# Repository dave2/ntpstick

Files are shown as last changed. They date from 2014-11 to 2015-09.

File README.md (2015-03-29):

ntpstick
========

NTPstick is a GPS-synced NTP server designed for low cost and ease
of deployment in places outside traditional datacentres.

The "stick" concept is that the board is expected to be placed into
a PVC tube at least 30mm I.D. with only an Ethernet cable reaching
the outside world carrying both Ethernet and poor-mans POE.

Structure
---------

This repo is divided into sections for different parts of the project:

 - hardware/ .. Contains the Kicad sources, schematics in PDF, and generated
   gerber files.
 - firmware/ .. Completed builds of the firmware, able to be flashed to 
   boards over TFTP
 - src/ .. Source code for the firmware.

Specifications
--------------

 - u.fl GPS antenna connection
 - uBlox MAX-M8Q GPS module (includes internal TCXO)
 - Atmel ATXMEGA128A4U MCU
 - 27MHz VCXO system clock
 - 12-bit DAC for VCXO control
 - WizNet W5500 Ethernet/IP chip
 - DC input on spare Ethernet pairs
 - DC-DC first stage, linear second stage PSU
 - Board is 113mm long, 30mm wide
 
License
-------

 - Please check each folder for the specific license applied, as they
   vary between sections of the project.

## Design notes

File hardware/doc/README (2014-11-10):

Contains various documents relating to the hardware.
May or may not be maintained. Schematics should be examined from 
the kicad source directory instead.

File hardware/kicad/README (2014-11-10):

Notes on Kicad source files for NTPstick
========================================

- These files require the current upstream source of Kicad to be read.
  In general, versions shipped with most distributions are not new 
  enough to read these files. At least r5256 is required from the Kicad
  source repo.

- I have not included separate libraries or footprints that were created
  for this project. I'll include them at some future point.

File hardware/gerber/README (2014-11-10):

********************************************************************
**                                                                **
**       W A R N I N G :   THESE FILES ARE NOT MAINTAINED         **
**                                                                **
********************************************************************

You should always generate gerbers from the Kicad source files. These
are here for reference about what versions were built at various stages.

DO NOT RELY ON THESE FILES FOR MANUFACTURE. ALWAYS GENERATE FROM KICAD.

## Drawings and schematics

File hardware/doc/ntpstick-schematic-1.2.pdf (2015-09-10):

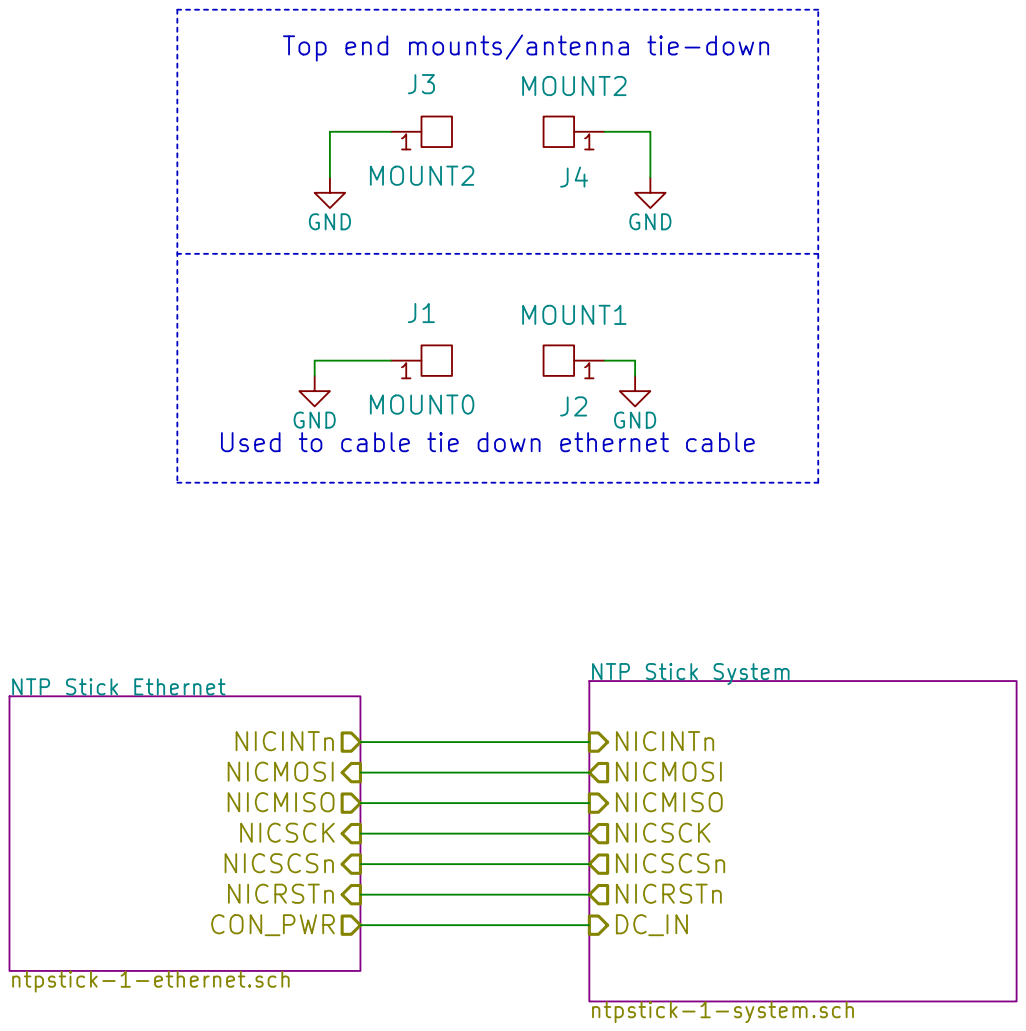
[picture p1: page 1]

1 J4 MOUNT2GND Top end mounts/antenna tie-down

1J1 MOUNT0
1 J2 MOUNT1 Used to cable tie down ethernet cable

File: ntpstick-1.sch Sheet: / hairy.geek.nz CC-NZ-3.0 BY-SA Not Production Proven NTP Stick Ethernet ntpstick-1-ethernet.sch

Id: 1/3 Title: NTP Stick 1.2

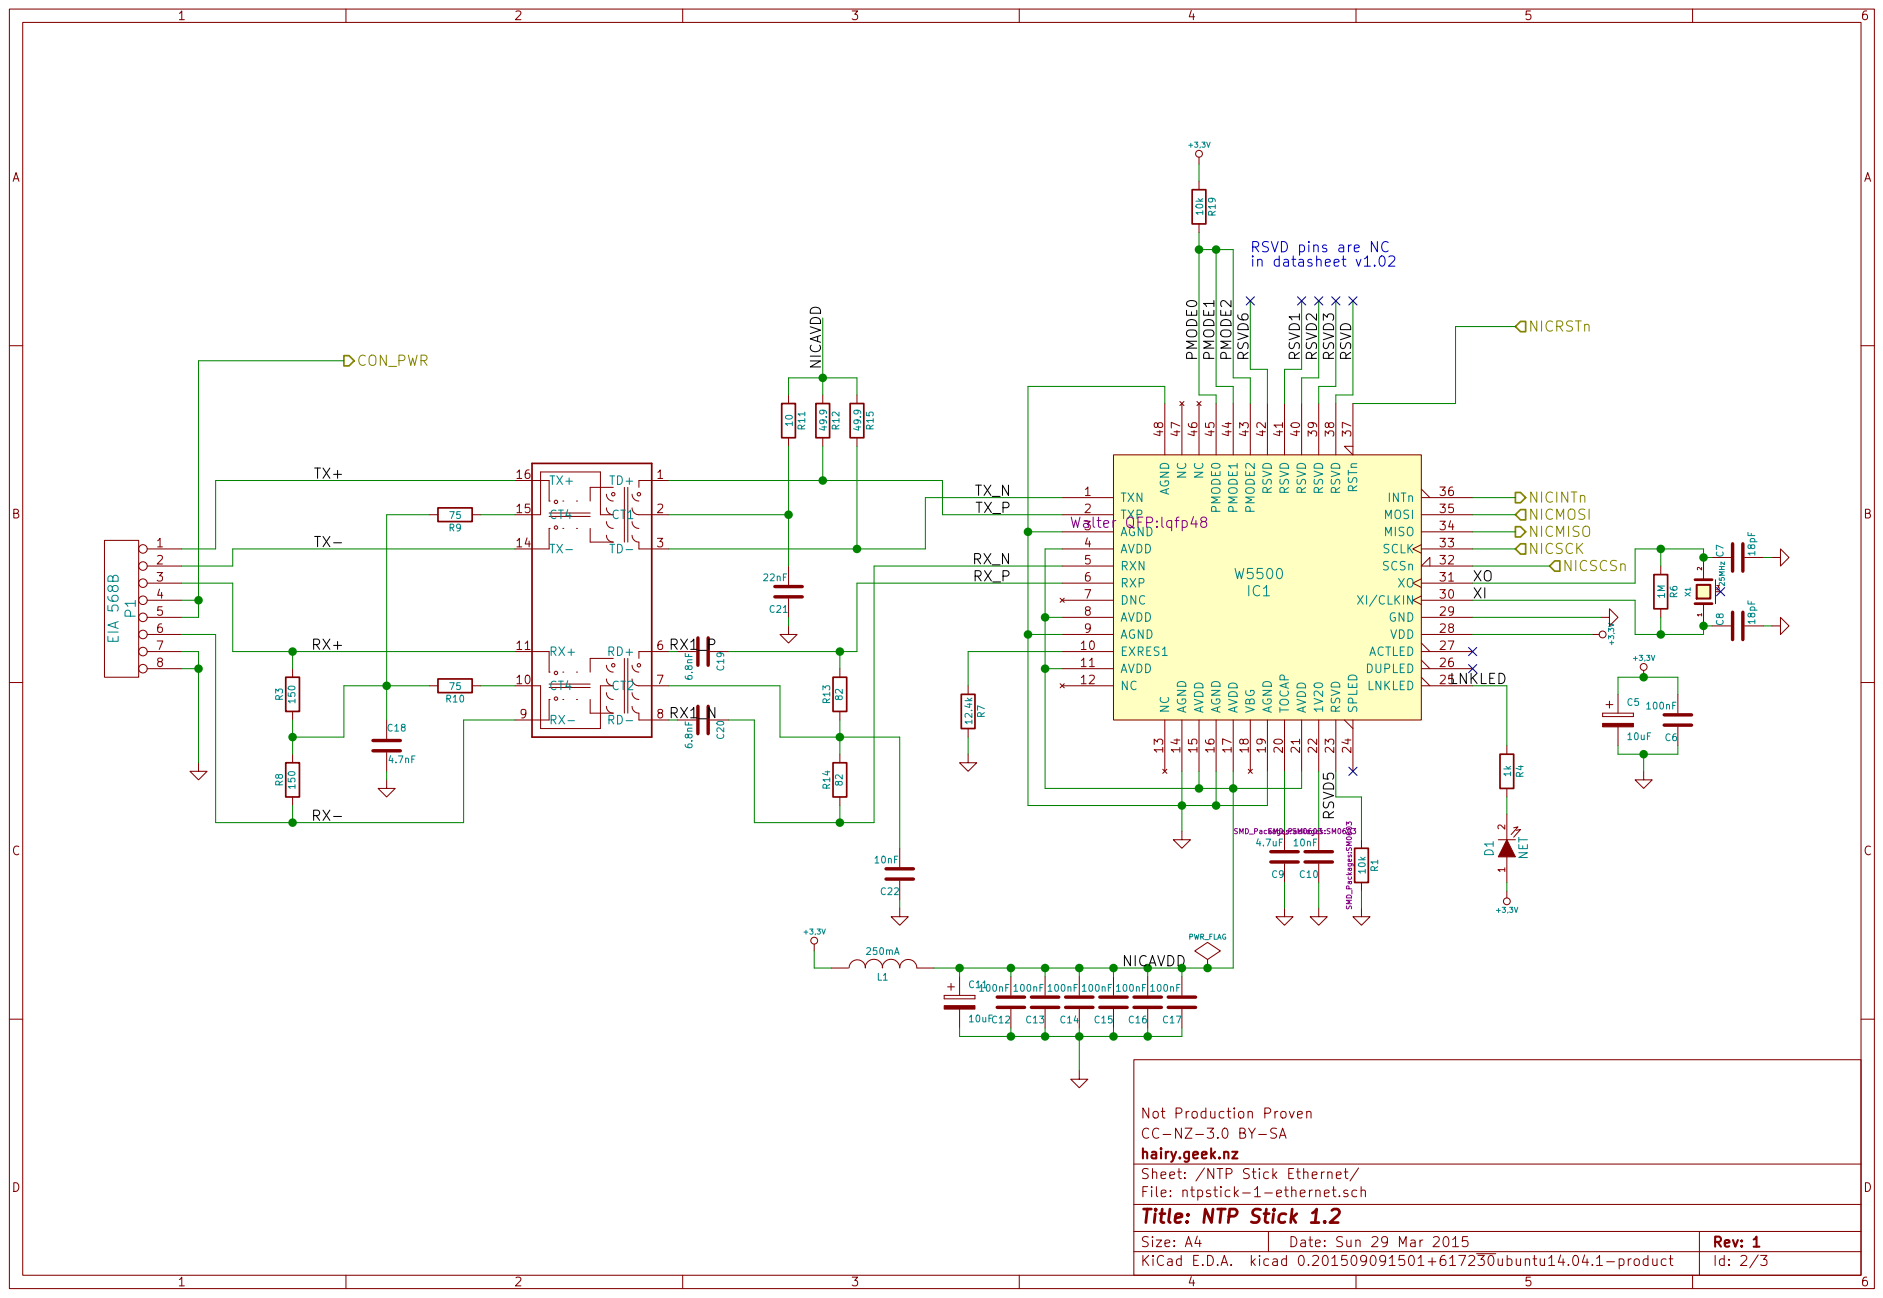
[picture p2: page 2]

RSVD pins are NC
in datasheet v1.02

RSVD1 RSVD2 RSVD3 RSVD RSVD5 IC1 W5500 Walter QFP:lqfp48 | XI PMODE0 PMODE1 PMODE2 RSVD6

File: ntpstick-1-ethernet.sch Sheet: /NTP Stick Ethernet/ hairy.geek.nz CC-NZ-3.0 BY-SA Not Production Proven

Id: 2/3 Title: NTP Stick 1.2

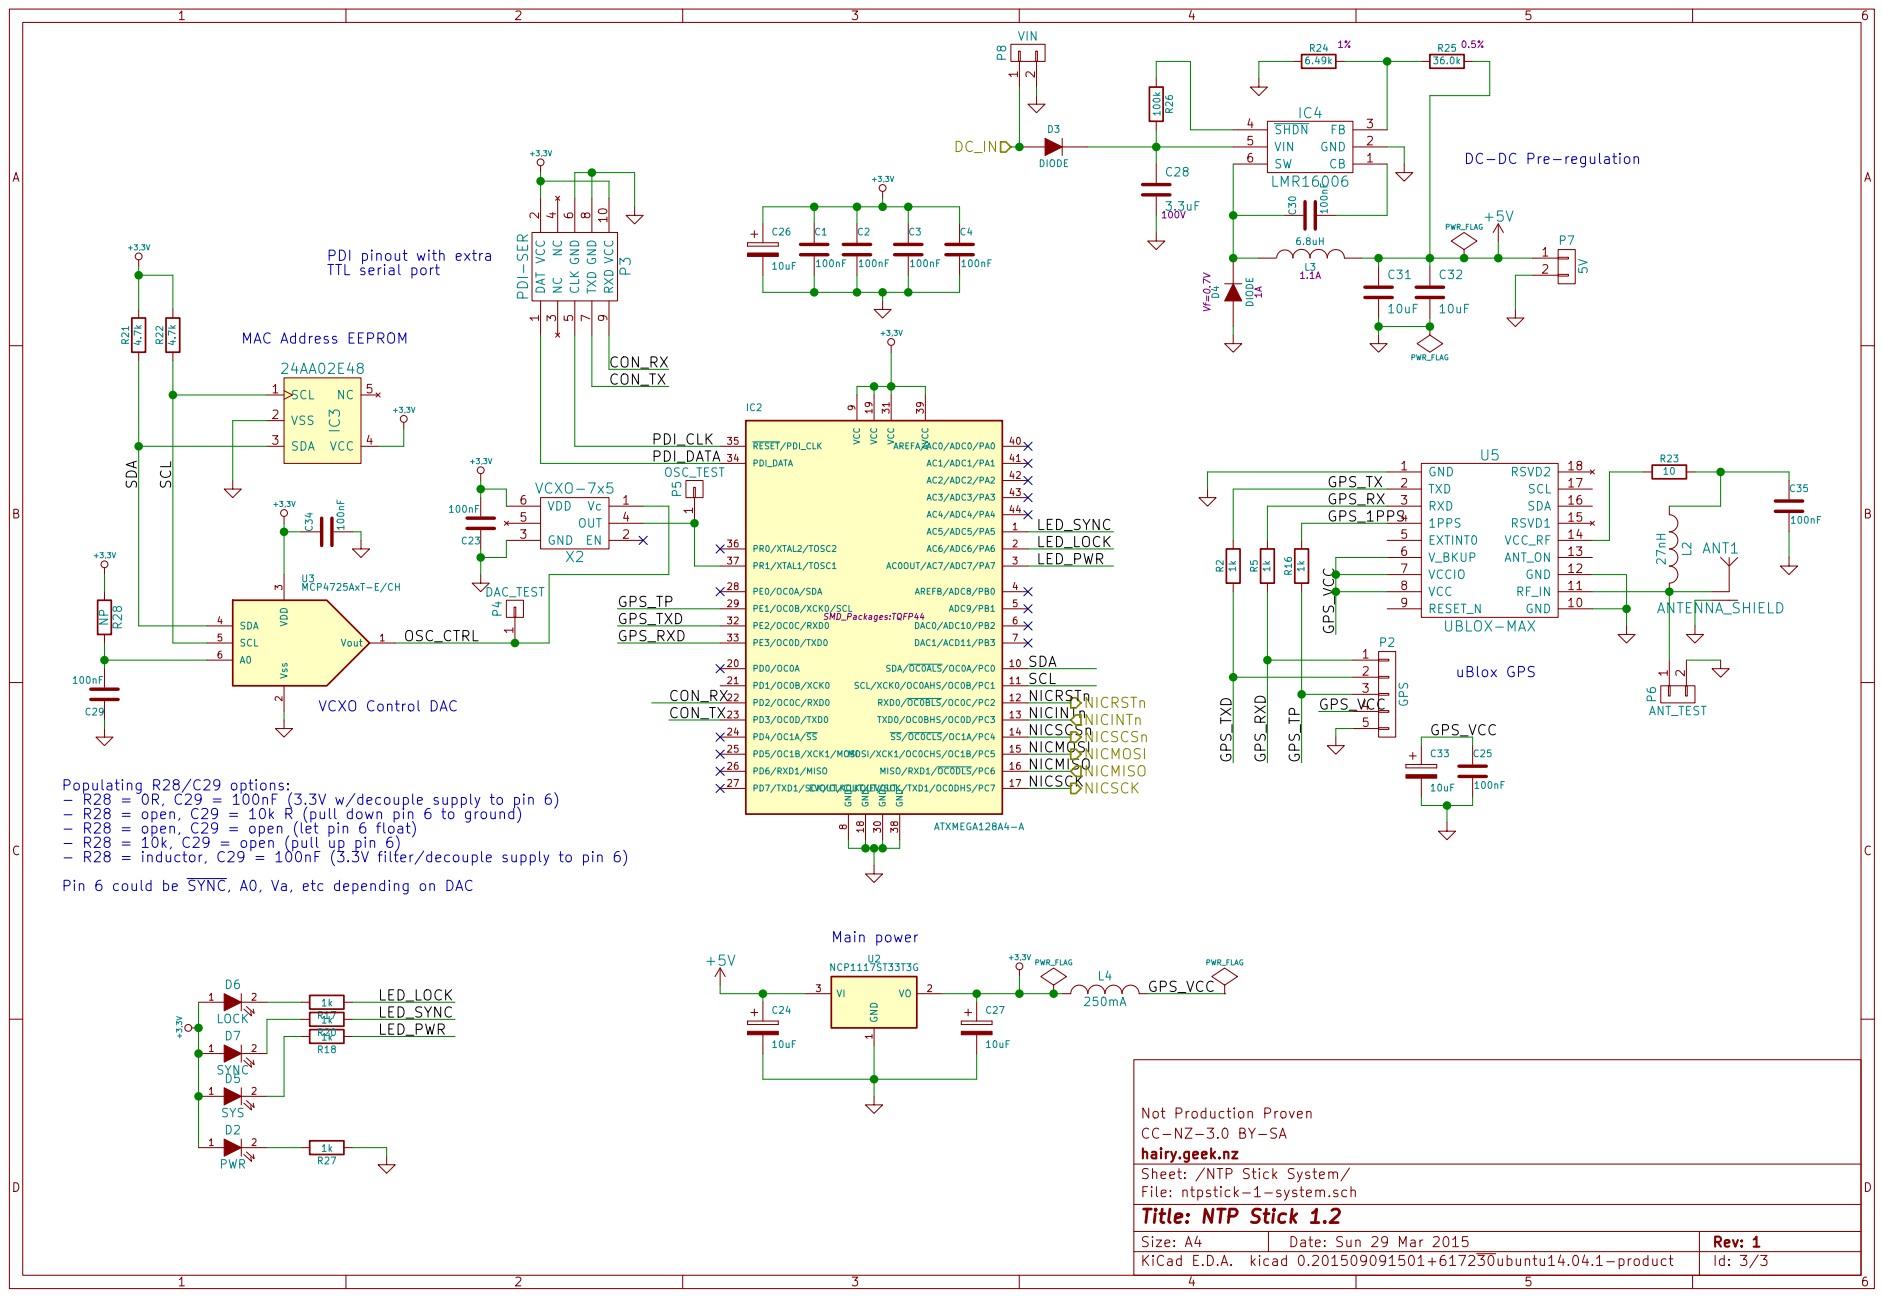
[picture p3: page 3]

DC-DC Pre-regulation

100nF VCXO Control DAC SCL

PDI pinout with extra

9 SDA/OC0ALS/OC0A/PC0 10 PD0/OC0A 20 GND 30 AREFA/AC0/ADC0/PA0 40 SCL/XCK0/OC0AHS/OC0B/PC1 11 PD1/OC0B/XCK0 21 VCC 31 AC1/ADC1/PA1 41 RXD0/OC0BLS/OC0C/PC2 12 PD2/OC0C/RXD0 22 PE2/OC0C/RXD0 32 AC2/ADC2/PA2 42

Populating R28/C29 options:
- R28 = 0R, C29 = 100nF (3.3V w/decouple supply to pin 6)
- R28 = open, C29 = 10k R (pull down pin 6 to ground)
- R28 = open, C29 = open (let pin 6 float)
- R28 = 10k, C29 = open (pull up pin 6)
- R28 = inductor, C29 = 100nF (3.3V filter/decouple supply to pin 6)

hairy.geek.nz CC-NZ-3.0 BY-SA Not Production Proven

Sheet: /NTP Stick System/
File: ntpstick-1-system.sch
Id: 3/3 Title: NTP Stick 1.2

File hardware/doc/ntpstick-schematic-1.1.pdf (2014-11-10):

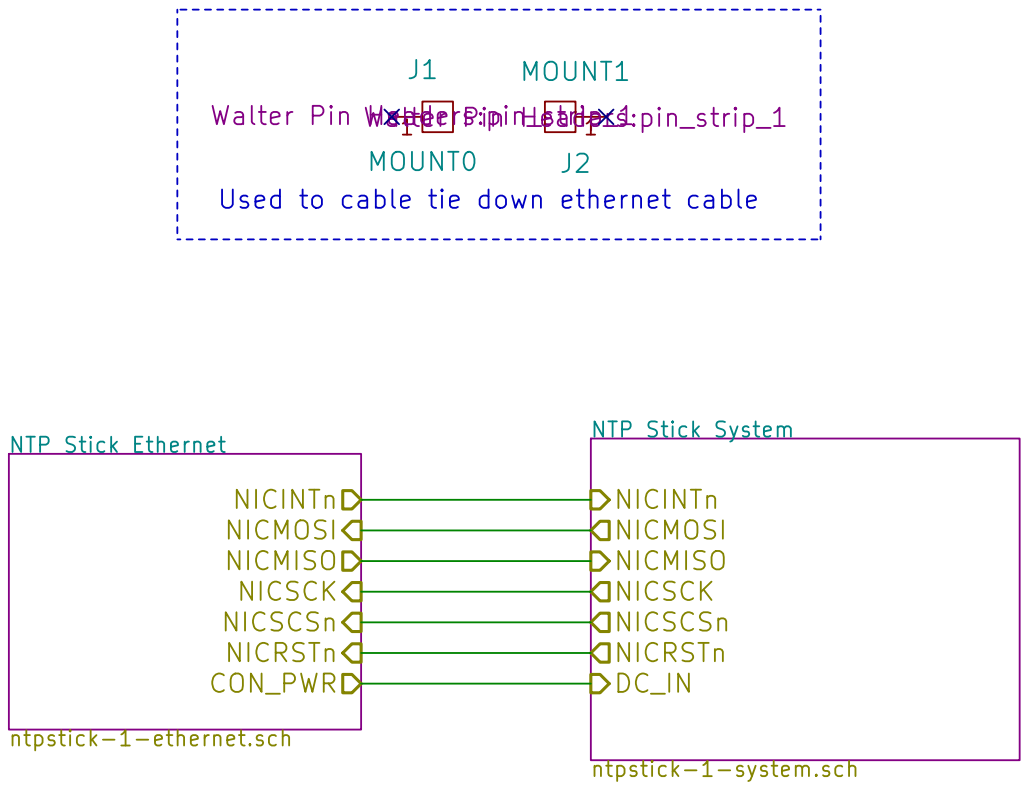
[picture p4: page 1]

Walter Pin Headers:pin_strip_11 J2 MOUNT1 Used to cable tie down ethernet cable

File: ntpstick-1.sch Sheet: / hairy.geek.nz CC BY-SA Not Production Proven NTP Stick Ethernet ntpstick-1-ethernet.sch

Id: 1/3 Title: NTP Stick 1.1

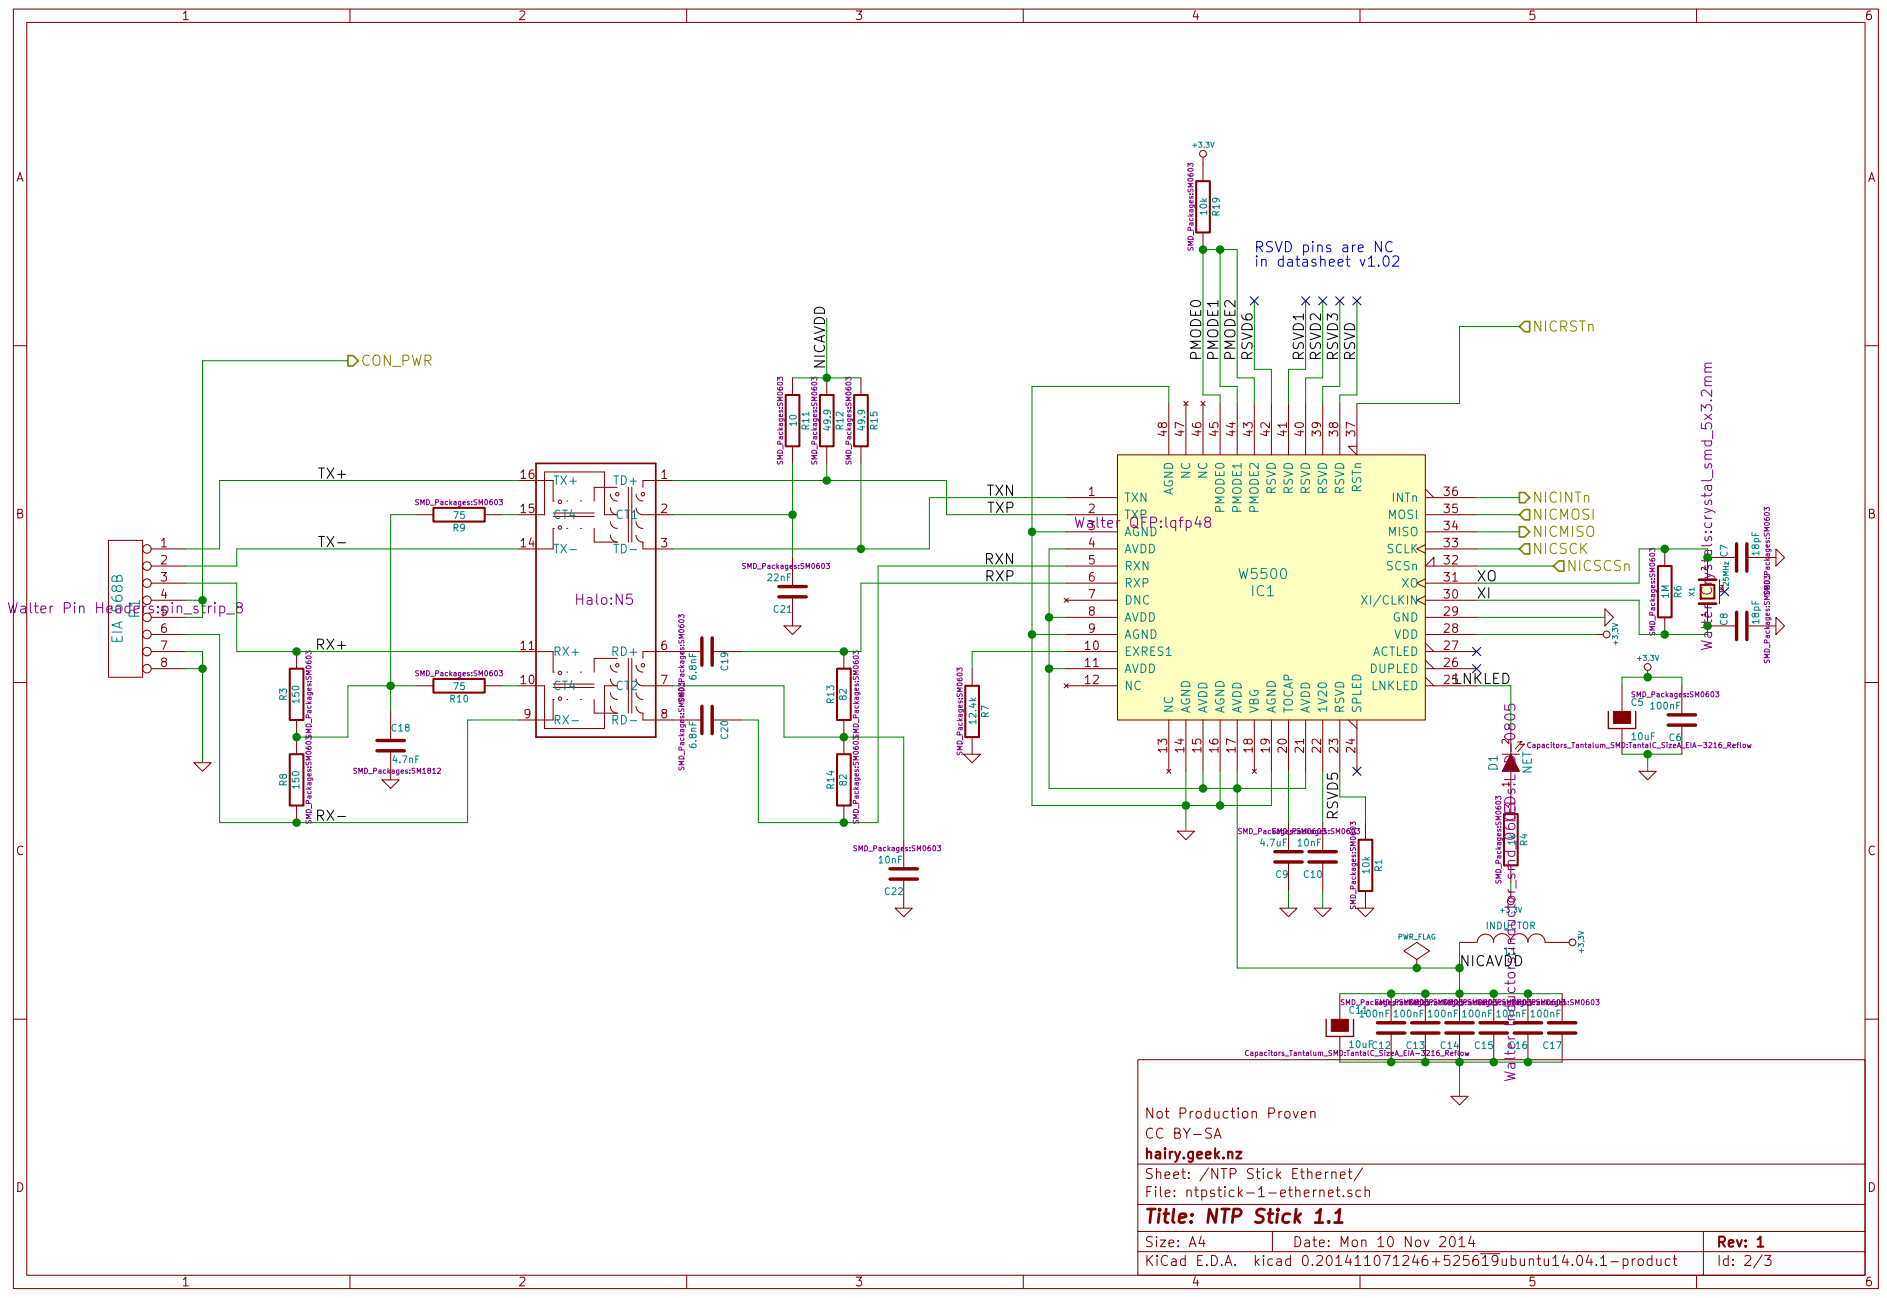
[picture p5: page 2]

RSVD1 RSVD2 RSVD3 RSVD RSVD5 IC1 W5500 Walter QFP:lqfp48 | XI PMODE0 PMODE1 PMODE2 RSVD6

8 P1 EIA 568B Walter Pin Headers:pin_strip_8

File: ntpstick-1-ethernet.sch Sheet: /NTP Stick Ethernet/ hairy.geek.nz CC BY-SA Not Production Proven

Id: 2/3 Title: NTP Stick 1.1

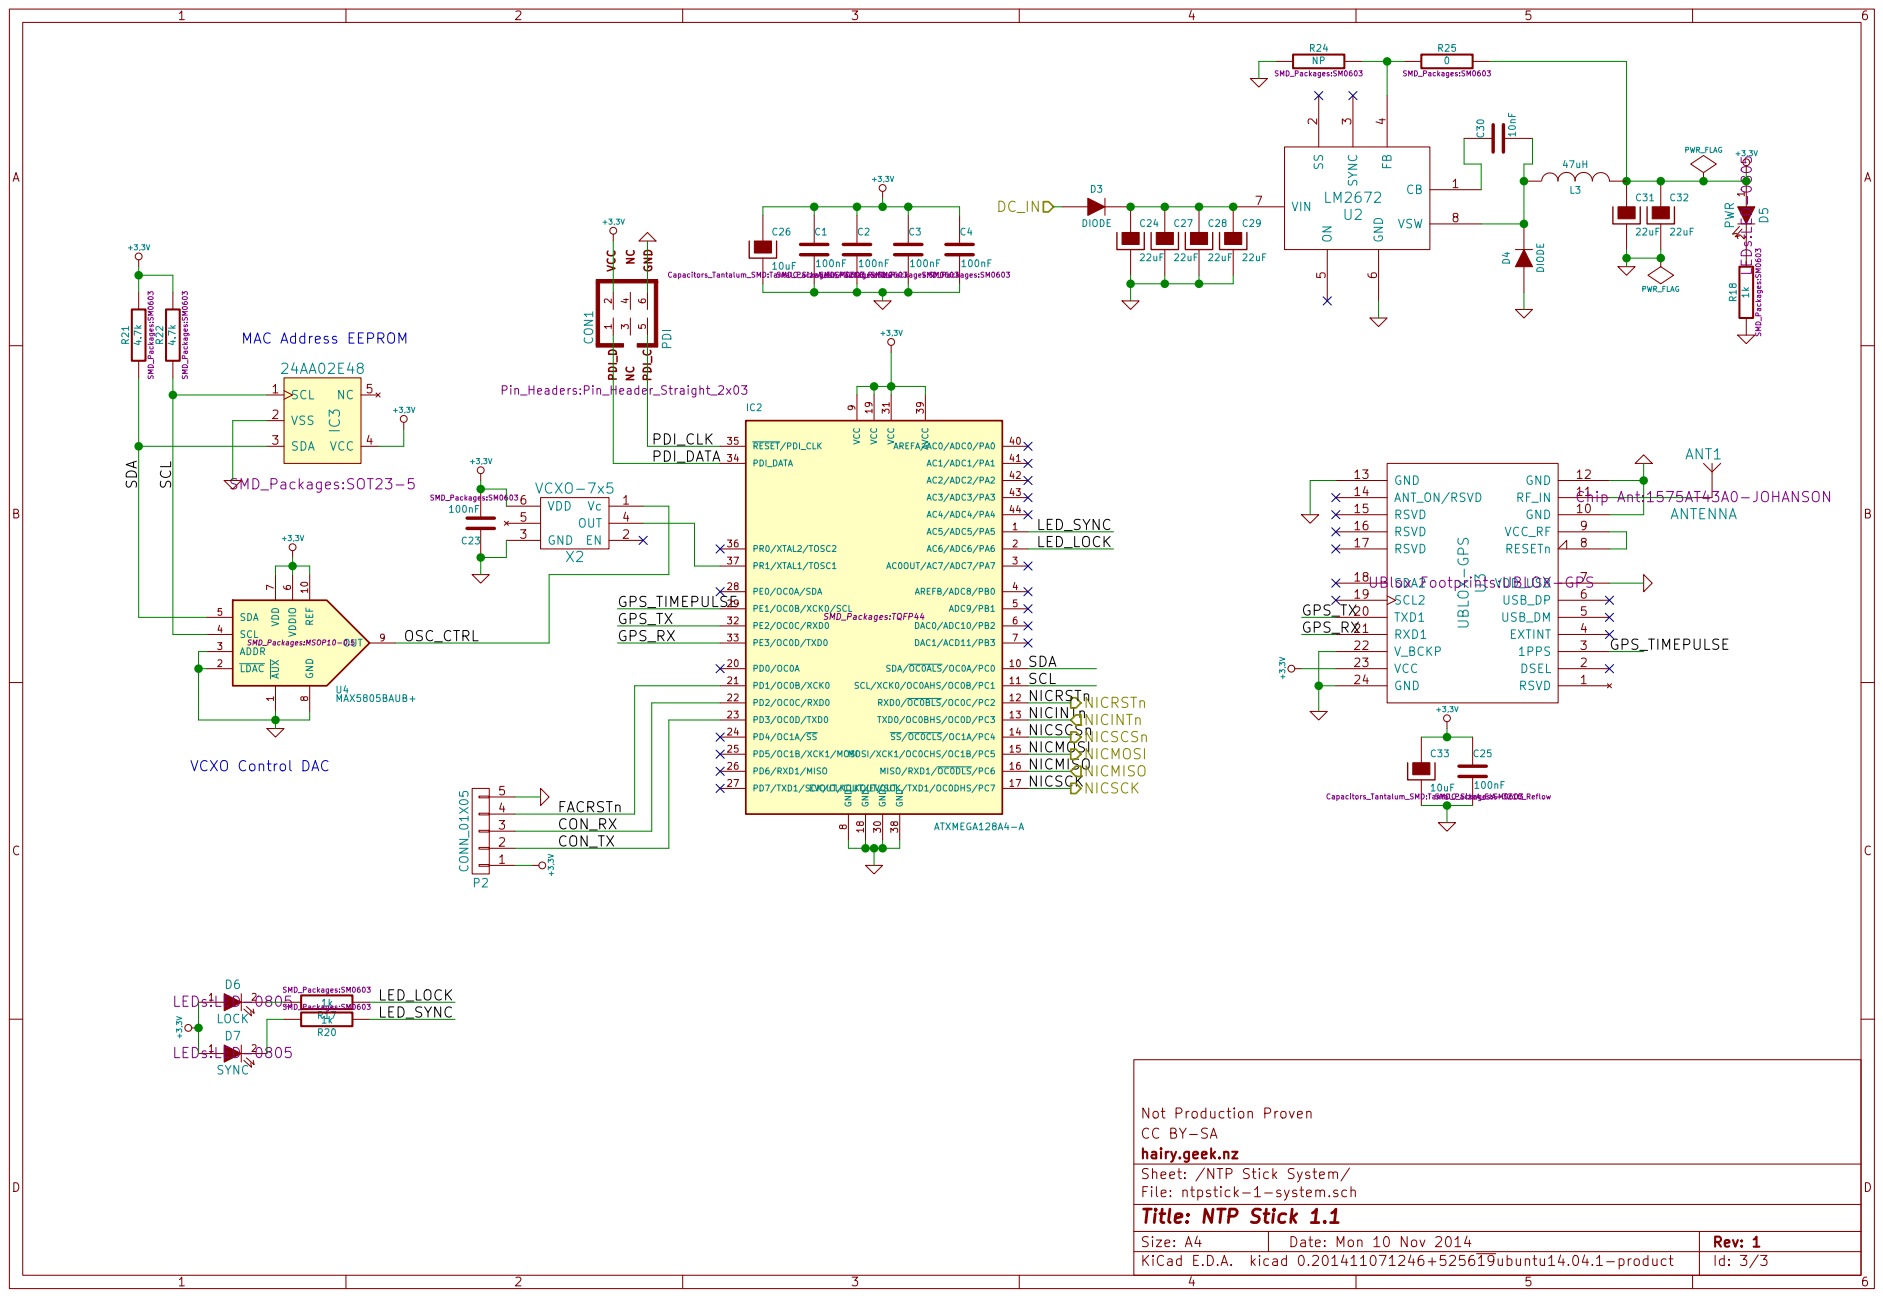
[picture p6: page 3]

9 SDA/OC0ALS/OC0A/PC0 10 PD0/OC0A 20 GND 30 AREFA/AC0/ADC0/PA0 40 SCL/XCK0/OC0AHS/OC0B/PC1 11 PD1/OC0B/XCK0 21 VCC 31 AC1/ADC1/PA1 41 RXD0/OC0BLS/OC0C/PC2 12 PD2/OC0C/RXD0 22 PE2/OC0C/RXD0 32 AC2/ADC2/PA2 42

SMD_Packages:MSOP10-0.5 VCXO Control DAC SCL

hairy.geek.nz CC BY-SA Not Production Proven

Sheet: /NTP Stick System/
File: ntpstick-1-system.sch
Id: 3/3 Title: NTP Stick 1.1

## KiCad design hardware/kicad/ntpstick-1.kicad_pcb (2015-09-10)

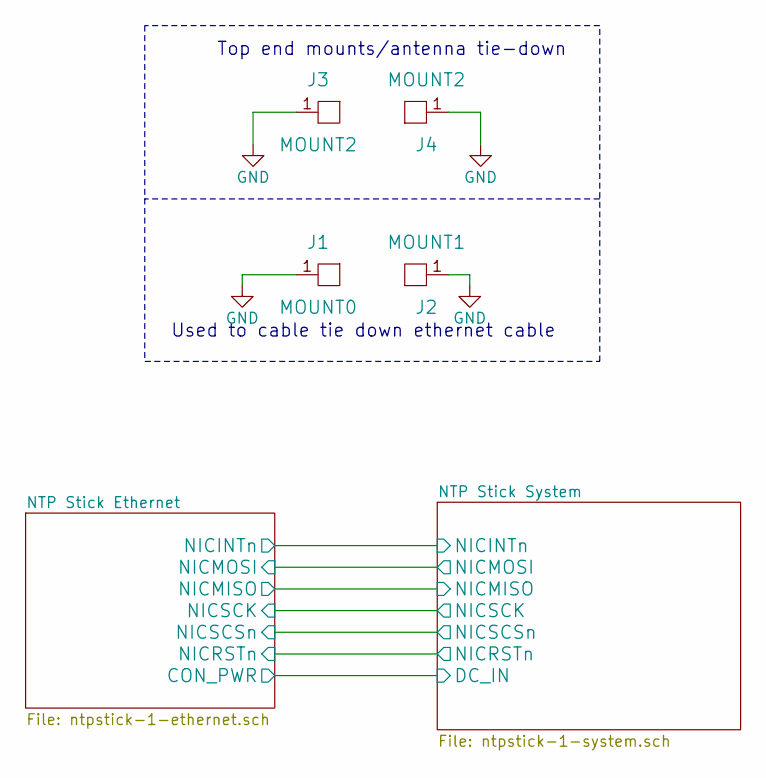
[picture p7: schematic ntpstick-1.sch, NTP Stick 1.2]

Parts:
J1: MOUNT0; 4-40-HOLE
J2: MOUNT1; 4-40-HOLE
J3, J4: MOUNT2; 4-40-HOLE

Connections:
GND: J1.1, J2.1, J3.1, J4.1; also elsewhere on the board

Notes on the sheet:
Used to cable tie down ethernet cable
Top end mounts/antenna tie-down

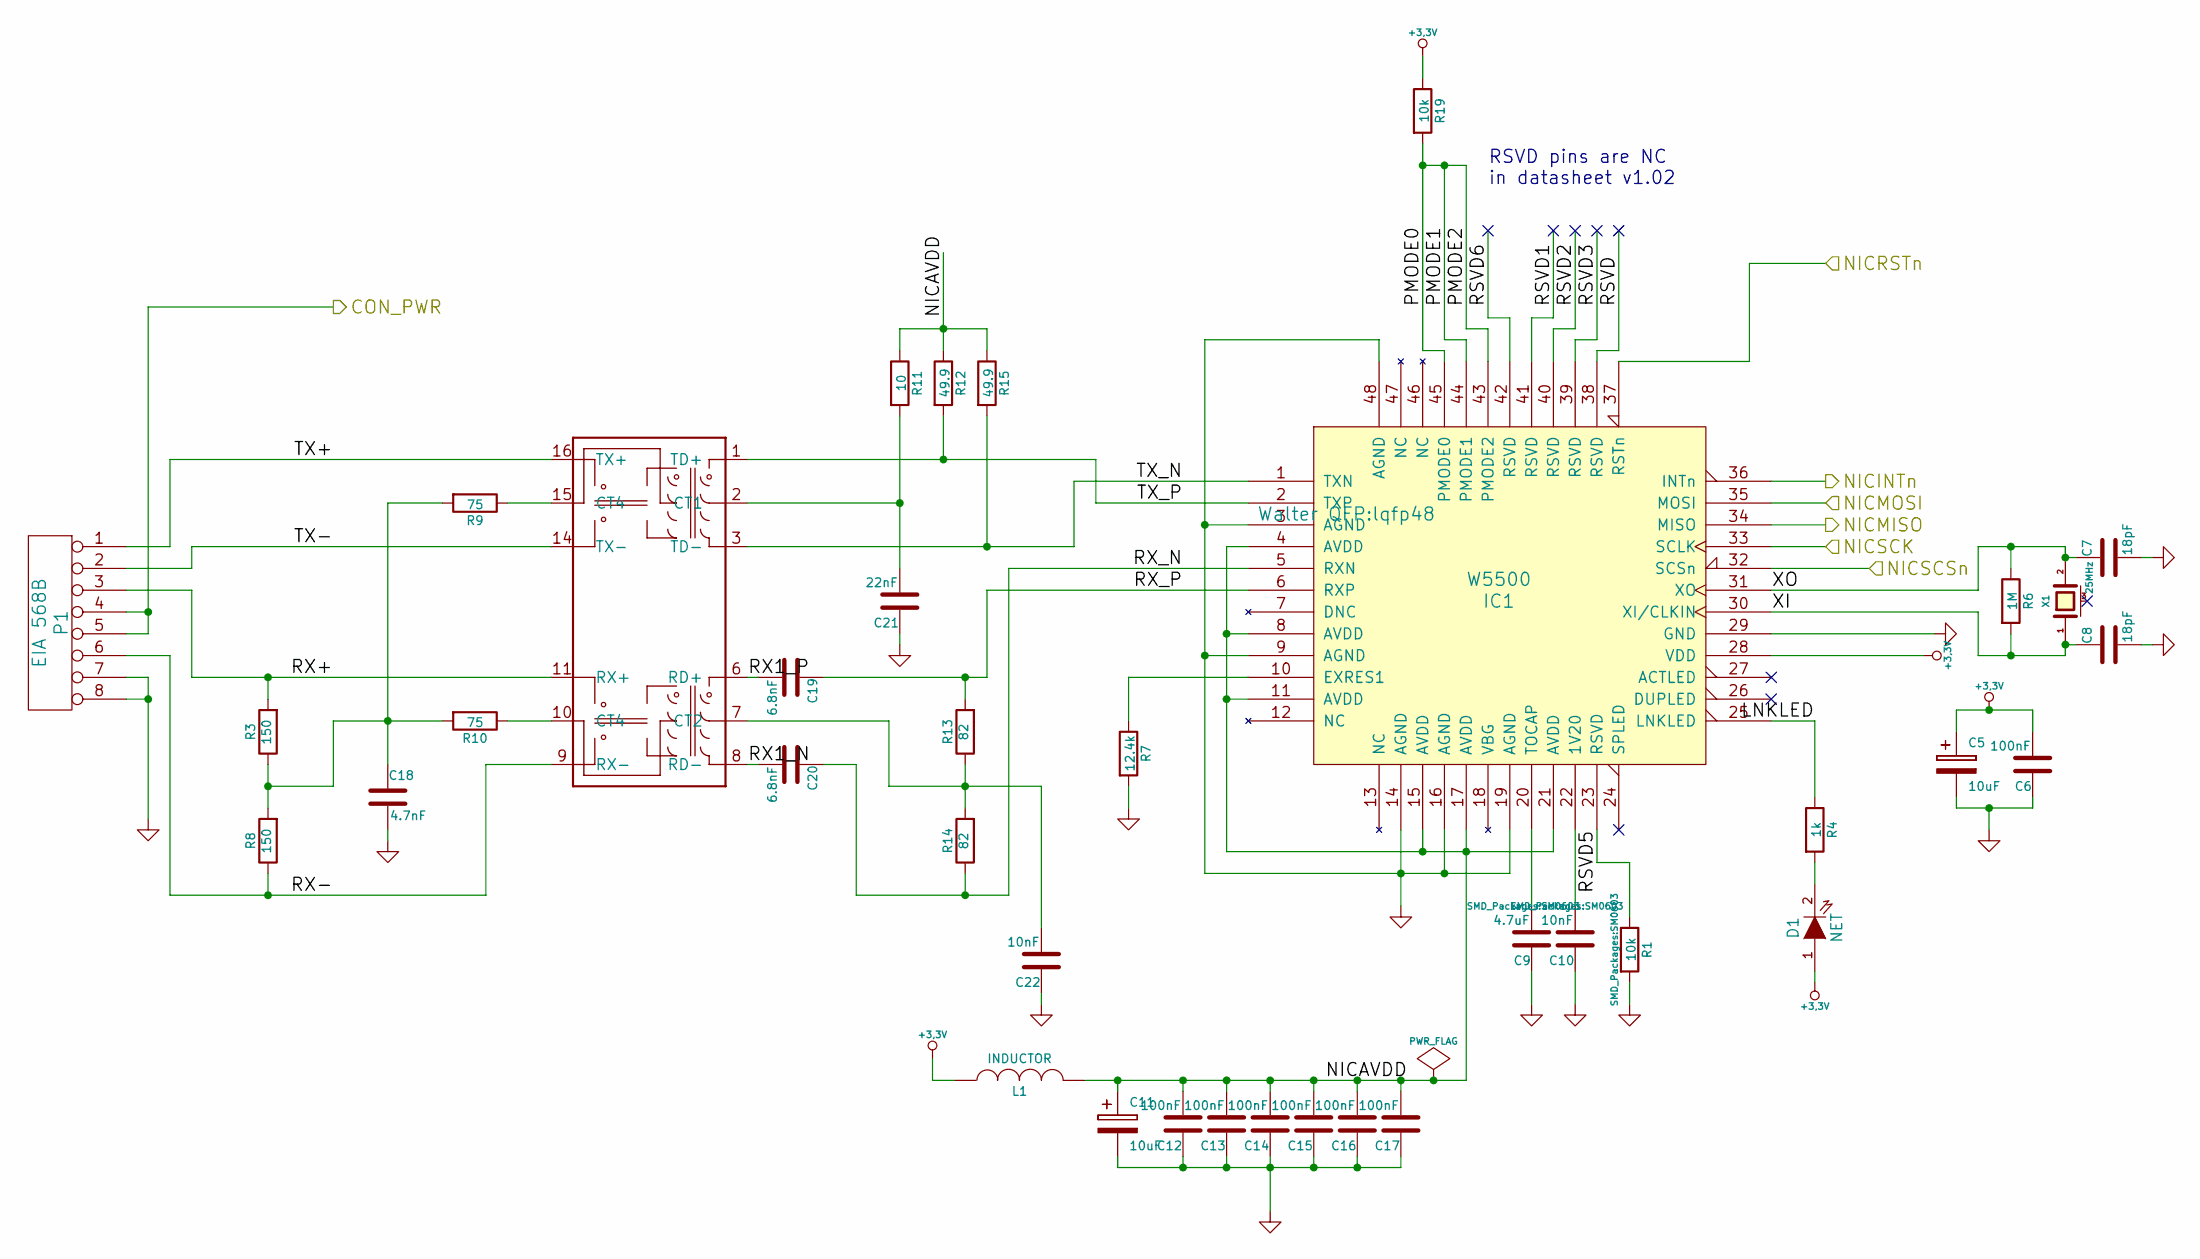
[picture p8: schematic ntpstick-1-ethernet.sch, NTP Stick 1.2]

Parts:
C5, C11: 10uF; c_tant_A; Voltage 16V
C6, C12, C13, C14, C15, C16, C17: 100nF; SM0603
C7, C8: 18pF; SM0603
C9: 4.7uF; SM0603
C10, C22: 10nF; SM0603
C18: 4.7nF; SM1812; Voltage 2kV
C19, C20: 6.8nF; SM0603
C21: 22nF; SM0603
D1: NET; LED-0805
IC1: W5500; lqfp48
L1: INDUCTOR; SM0603
P1: EIA 568B; pin_strip_8
R1, R19: 10k; SM0603
R3, R8: 150; SM0603
R4: 1k; SM0603
R6: 1M; SM0603
R7: 12.4k; SM0603
R9, R10: 75; SM0603
R11: 10; SM0603
R12, R15: 49.9; SM0603
R13, R14: 82; SM0603
U1: TG110-E*N5_N5; N5
X1: 25MHz; crystal_smd_5x3.2mm

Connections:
+3.3V: C5.1, C6.2, D1.1 (A), IC1.28 (VDD), L1.1, R19.1; also elsewhere on the board
/NTP Stick Ethernet/CON_PWR: P1.4, P1.5; also elsewhere on the board
/NTP Stick Ethernet/LNKLED: IC1.25 (LNKLED), R4.1
/NTP Stick Ethernet/NICAVDD: C11.1, C12.2, C13.2, C14.2, C15.2, C16.2, C17.2, IC1.4 (AVDD), IC1.8 (AVDD), IC1.11 (AVDD), IC1.15 (AVDD), IC1.17 (AVDD), IC1.21 (AVDD), L1.2, R11.1, R12.1, R15.1
/NTP Stick Ethernet/NICINTn: IC1.36 (INTn); also elsewhere on the board
/NTP Stick Ethernet/NICMISO: IC1.34 (MISO); also elsewhere on the board
/NTP Stick Ethernet/NICMOSI: IC1.35 (MOSI); also elsewhere on the board
/NTP Stick Ethernet/NICRSTn: IC1.37 (RSTn); also elsewhere on the board
/NTP Stick Ethernet/NICSCK: IC1.33 (SCLK); also elsewhere on the board
/NTP Stick Ethernet/NICSCSn: IC1.32 (SCSn); also elsewhere on the board
/NTP Stick Ethernet/PMODE0: IC1.43 (PMODE2), IC1.44 (PMODE1), IC1.45 (PMODE0), R19.2
/NTP Stick Ethernet/RSVD: IC1.38 (RSVD)
/NTP Stick Ethernet/RSVD1: IC1.41 (RSVD)
/NTP Stick Ethernet/RSVD2: IC1.40 (RSVD)
/NTP Stick Ethernet/RSVD3: IC1.39 (RSVD)
/NTP Stick Ethernet/RSVD5: IC1.23 (RSVD), R1.1
/NTP Stick Ethernet/RSVD6: IC1.42 (RSVD)
/NTP Stick Ethernet/RX1_N: C20.2, U1.8 (RD-)
/NTP Stick Ethernet/RX1_P: C19.2, U1.6 (RD+)
/NTP Stick Ethernet/RX+: P1.3, R3.2, U1.11 (RX+)
/NTP Stick Ethernet/RX-: P1.6, R8.1, U1.9 (RX-)
/NTP Stick Ethernet/RX_N: C20.1, IC1.5 (RXN), R14.1
/NTP Stick Ethernet/RX_P: C19.1, IC1.6 (RXP), R13.2
/NTP Stick Ethernet/TX+: P1.1, U1.16 (TX+)
/NTP Stick Ethernet/TX-: P1.2, U1.14 (TX-)
/NTP Stick Ethernet/TX_N: IC1.1 (TXN), R15.2, U1.3 (TD-)
/NTP Stick Ethernet/TX_P: IC1.2 (TXP), R12.2, U1.1 (TD+)
/NTP Stick Ethernet/XI: C8.1, IC1.30 (XI/CLKIN), R6.2, X1.1
/NTP Stick Ethernet/XO: C7.1, IC1.31 (XO), R6.1, X1.2
GND: C5.2, C6.1, C7.2, C8.2, C9.1, C10.1, C11.2, C12.1, C13.1, C14.1, C15.1, C16.1, C17.1, C18.2, C21.1, C22.1, IC1.3 (AGND), IC1.9 (AGND), IC1.14 (AGND), IC1.16 (AGND), IC1.19 (AGND), IC1.29 (GND), IC1.48 (AGND), P1.7, P1.8, R1.2, R7.2; also elsewhere on the board
unnamed: C9.2, IC1.20 (TOCAP)
unnamed: C10.2, IC1.22 (1V20)
unnamed: C18.1, R3.1, R8.2, R9.2, R10.2
unnamed: C21.2, R11.2, U1.2 (CT1)
unnamed: C22.2, R13.1, R14.2, U1.7 (CT2)
unnamed: D1.2 (K), R4.2
unnamed: IC1.10 (EXRES1), R7.1
unnamed: R9.1, U1.15 (CT4)
unnamed: R10.1, U1.10 (CT4)

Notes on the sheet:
RSVD pins are NC in datasheet v1.02

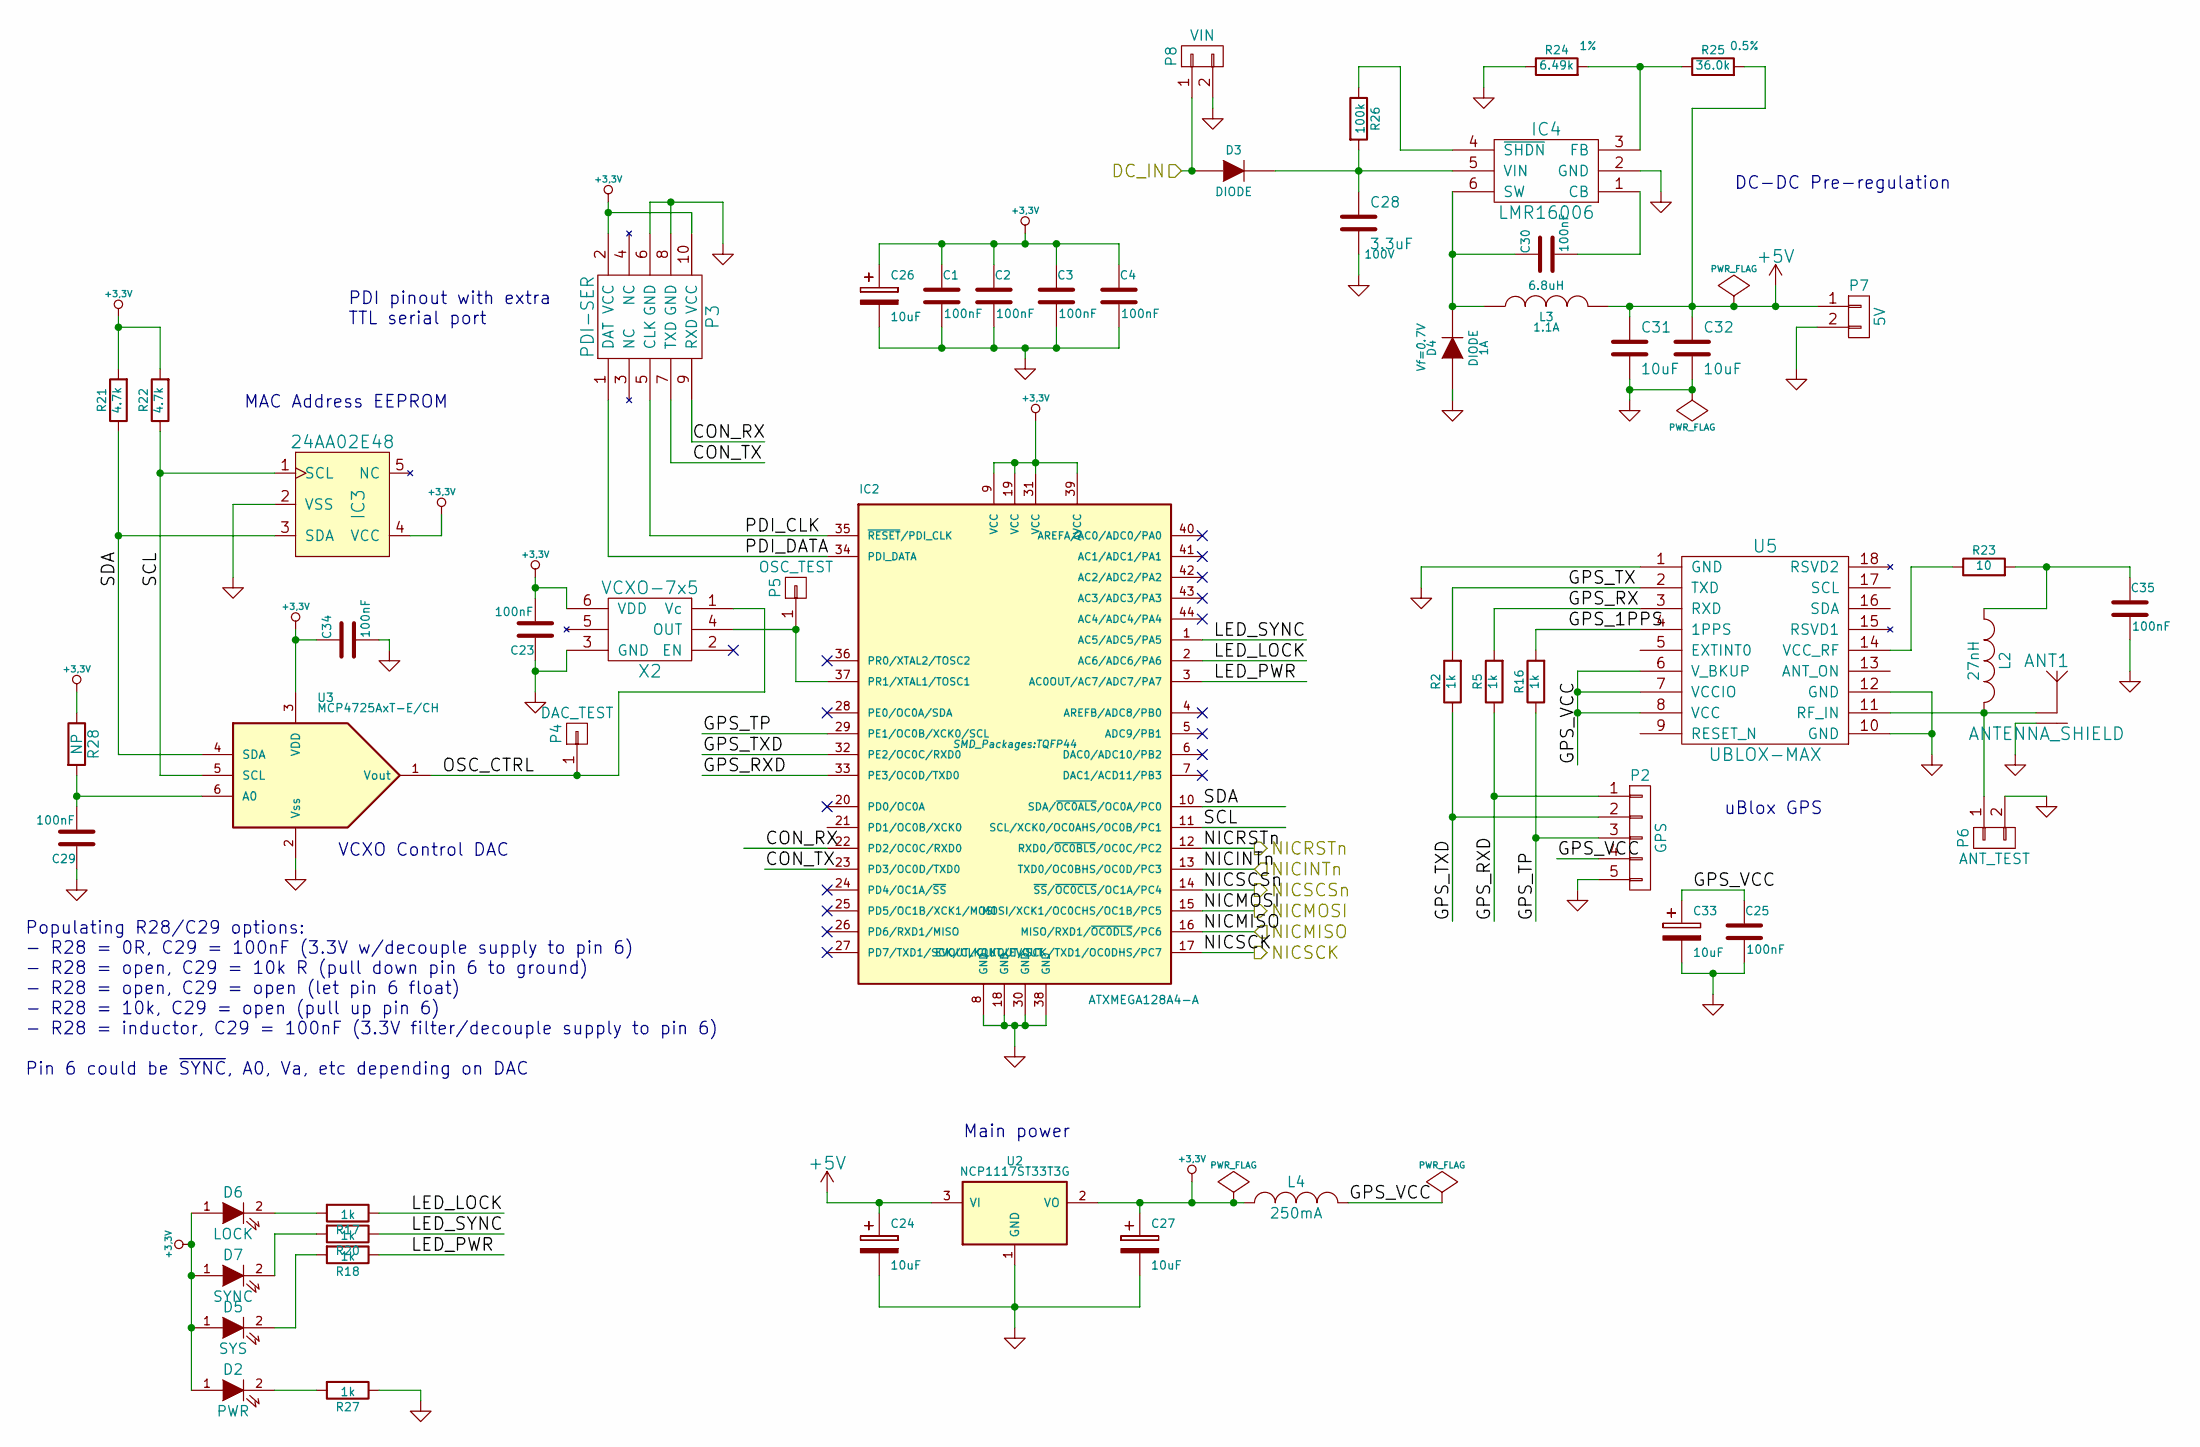
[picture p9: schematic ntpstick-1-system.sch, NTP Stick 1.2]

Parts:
ANT1: ANTENNA_SHIELD; coaxial_u.fl-r-smt-1
C1, C2, C3, C4, C23, C25, C29, C30, C34, C35: 100nF; SM0603
C24, C26, C27, C33: 10uF; c_tant_A; Voltage 16V
C28: 3.3uF; SM1210; Voltage 100V
C31, C32: 10uF; c_1206
D2: PWR; LED-0805
D3, D4: DIODE; do214ac
D5: SYS; LED-0805
D6: LOCK; LED-0805
D7: SYNC; LED-0805
IC2: ATXMEGA128A4-A; TQFP44
IC3: 24AA02E48; SOT23-5
IC4: LMR16006; SOT23_6
L2: 27nH; SM0603
L3: 6.8uH; inductor_bourns_srn5040
L4: 250mA; SM0603
P2: GPS; Pin_Header_Straight_1x05
P3: PDI-SER; Pin_Header_Straight_2x05
P4: DAC_TEST; Measurement_Point_Round-SMD-Pad_Small
P5: OSC_TEST; Measurement_Point_Round-SMD-Pad_Small
P6: ANT_TEST; Pin_Header_Straight_1x02
P7: 5V; Pin_Header_Straight_1x02
P8: VIN; Pin_Header_Straight_1x02
R2, R5, R16, R17, R18, R20, R27: 1k; SM0603
R21, R22: 4.7k; SM0603
R23: 10; SM0603
R24: 6.49k; SM0603
R25: 36.0k; SM0603
R26: 100k; SM0603
R28: NP; SM0603
U2: NCP1117ST33T3G; SOT223
U3: MCP4725AxT-E/CH; SOT23_6
U5: UBLOX-MAX; UBLOX-MAX-8-POLY
X2: VCXO-7x5; vcxo-7x5

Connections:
+3.3V: C1.1, C2.1, C3.1, C4.1, C23.2, C26.1, C27.1, C34.1, D2.1 (A), D5.1 (A), D6.1 (A), D7.1 (A), IC2.9 (VCC), IC2.19 (VCC), IC2.31 (VCC), IC2.39 (AVCC), IC3.4 (VCC), L4.1, P3.2 (VCC), P3.10 (VCC), R21.2, R22.2, R28.1, U2.2 (VO), U3.3 (VDD), X2.6 (VDD); also elsewhere on the board
+5V: C24.1, C31.1, C32.1, L3.2, P7.1, R25.2, U2.3 (VI)
/NTP Stick Ethernet/CON_PWR: D3.1 (A), P8.1; also elsewhere on the board
/NTP Stick Ethernet/NICINTn: IC2.13 (TXD0/OC0BHS/OC0D/PC3); also elsewhere on the board
/NTP Stick Ethernet/NICMISO: IC2.16 (MISO/RXD1/~OC0DLS~/PC6); also elsewhere on the board
/NTP Stick Ethernet/NICMOSI: IC2.15 (MOSI/XCK1/OC0CHS/OC1B/PC5); also elsewhere on the board
/NTP Stick Ethernet/NICRSTn: IC2.12 (RXD0/~OC0BLS~/OC0C/PC2); also elsewhere on the board
/NTP Stick Ethernet/NICSCK: IC2.17 (EVOUT/CLKOUT/SCK/TXD1/OC0DHS/PC7); also elsewhere on the board
/NTP Stick Ethernet/NICSCSn: IC2.14 (~SS~/~OC0CLS~/OC1A/PC4); also elsewhere on the board
/NTP Stick System/CON_RX: IC2.22 (PD2/OC0C/RXD0), P3.9 (RXD)
/NTP Stick System/CON_TX: IC2.23 (PD3/OC0D/TXD0), P3.7 (TXD)
/NTP Stick System/GPS_1PPS: R16.2, U5.4 (1PPS)
/NTP Stick System/GPS_RX: R5.2, U5.3 (RXD)
/NTP Stick System/GPS_RXD: IC2.33 (PE3/OC0D/TXD0), P2.1, R5.1
/NTP Stick System/GPS_TP: IC2.29 (PE1/OC0B/XCK0/SCL), P2.3, R16.1
/NTP Stick System/GPS_TX: R2.2, U5.2 (TXD)
/NTP Stick System/GPS_TXD: IC2.32 (PE2/OC0C/RXD0), P2.2, R2.1
/NTP Stick System/GPS_VCC: C25.1, C33.1, L4.2, P2.4, U5.6 (V_BKUP), U5.7 (VCCIO), U5.8 (VCC)
/NTP Stick System/LED_LOCK: IC2.2 (AC6/ADC6/PA6), R17.1
/NTP Stick System/LED_PWR: IC2.3 (AC0OUT/AC7/ADC7/PA7), R18.1
/NTP Stick System/LED_SYNC: IC2.1 (AC5/ADC5/PA5), R20.1
/NTP Stick System/OSC_CTRL: P4.1, U3.1 (Vout), X2.1 (Vc)
/NTP Stick System/PDI_CLK: IC2.35 (~RESET~/PDI_CLK), P3.5 (CLK)
/NTP Stick System/PDI_DATA: IC2.34 (PDI_DATA), P3.1 (DAT)
/NTP Stick System/SCL: IC2.11 (SCL/XCK0/OC0AHS/OC0B/PC1), IC3.1 (SCL), R22.1, U3.5 (SCL)
/NTP Stick System/SDA: IC2.10 (SDA/~OC0ALS~/OC0A/PC0), IC3.3 (SDA), R21.1, U3.4 (SDA)
GND: ANT1.2, C1.2, C2.2, C3.2, C4.2, C23.1, C24.2, C25.2, C26.2, C27.2, C28.2, C29.1, C31.2, C32.2, C33.2, C34.2, C35.2, D4.1 (A), IC2.8 (GND), IC2.18 (GND), IC2.30 (GND), IC2.38 (GND), IC3.2 (VSS), IC4.2 (GND), P2.5, P3.6 (GND), P3.8 (GND), P6.2, P7.2, P8.2, R24.1, R27.1, U2.1 (GND), U3.2 (Vss), U5.1 (GND), U5.10 (GND), U5.12 (GND), X2.3 (GND); also elsewhere on the board
unnamed: ANT1.1, L2.2, P6.1, U5.11 (RF_IN)
unnamed: C28.1, D3.2 (K), IC4.5 (VIN), R26.2
unnamed: C29.2, R28.2, U3.6 (A0)
unnamed: C30.1, D4.2 (K), IC4.6 (SW), L3.1
unnamed: C30.2, IC4.1 (CB)
unnamed: C35.1, L2.1, R23.2
unnamed: D2.2 (K), R27.2
unnamed: D5.2 (K), R18.2
unnamed: D6.2 (K), R17.2
unnamed: D7.2 (K), R20.2
unnamed: IC2.37 (PR1/XTAL1/TOSC1), P5.1, X2.4 (OUT)
unnamed: IC4.3 (FB), R24.2, R25.1
unnamed: IC4.4 (~SHDN~), R26.1
unnamed: R23.1, U5.14 (VCC_RF)

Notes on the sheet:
MAC Address EEPROM
VCXO Control DAC
DC-DC Pre-regulation
PDI pinout with extra TTL serial port
Main power
uBlox GPS
Populating R28/C29 options: - R28 = 0R, C29 = 100nF (3.3V w/decouple supply to pin 6) - R28 = open, C29 = 10k R (pull down pin 6 to ground) - R28 = open, C29 = open (let pin 6 float) - R28 = 10k, C29 = open (pull up pin 6) - R28 = inductor, C29 = 100nF (3.3V filter/decouple supply to pin 6) Pin 6 c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

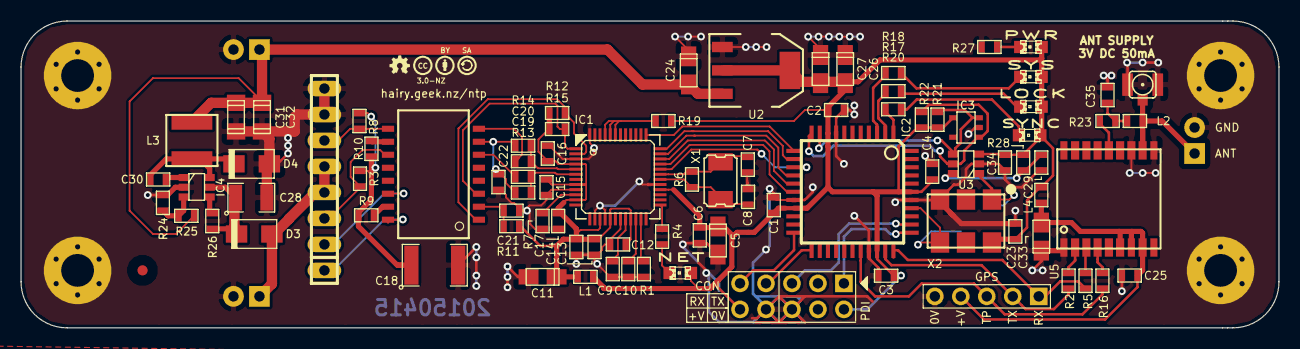
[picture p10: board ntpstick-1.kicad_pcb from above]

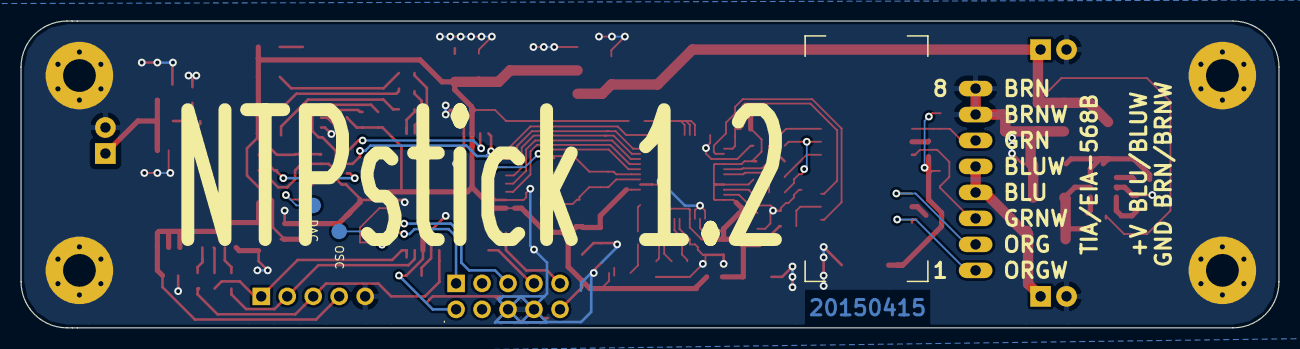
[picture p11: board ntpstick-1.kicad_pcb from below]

Board: 2 copper layers, 123.0 x 30.0 mm, 103 parts (3 on the bottom side), 66 nets.

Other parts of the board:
FIDUCIAL: val**; FIDUCIAL
LOGO_CC: VAL**; LOGO_CC_1.9mm
LOGO_CC_BY: VAL**; LOGO_CC_BY_1.9mm
LOGO_CC_SA: VAL**; LOGO_CC_SA_1.9mm
LOGO_OSHW_silkscreen_2mm: val**; LOGO_OSHW_silkscreen_2mm
SERIAL_LABEL: VAL**; SERIAL_LABEL

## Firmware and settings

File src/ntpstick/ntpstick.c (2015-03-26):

/* Copyright (C) 2014 David Zanetti
 *
 * This file is part of ntpstick
 *
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
 * If not, see <http://www.gnu.org/licenses/>.
 */

#include <stdio.h>
#include <stdlib.h>
#include <string.h>
#include "ntpstick.h"
#include <libkakapo/global.h>
#include <avr/io.h>
#include <util/delay.h>
#include <avr/interrupt.h>
#include <avr/sleep.h>
#include <avr/eeprom.h>
#include <avr/pgmspace.h>
#include <libkakapo/clock.h>
#include <libkakapo/usart.h>
#include <libkakapo/errors.h>
#include <libkakapo/spi.h>
#include <libkakapo/twi.h>
#include <libkakapo/net_w5500.h>
#include <libkakapo/nvm.h>
#include "console.h"
#include "max580x.h"

/* hook to get processing of debug working */
void debugcon_hook(uint8_t c);
void gps_hook(uint8_t c);
void telnetd_hook(uint8_t socket, w5500_event_t event);

volatile uint8_t flags;
#define FLAG_DEBUGCON 0x01
#define FLAG_TELNETD0 0x02
#define FLAG_TELNETD1 0x04
#define FLAG_W5500 0x08
#define FLAG_GPS 0x10
#define FLAG_TELNET_OPEN 0x20

#undef DEBUG_GPS_PASS

#define I2C_PORT_MAC twi_c
#define I2C_PORT_DAC twi_c

/* global variables needed from eeprom */
/* note: these are placeholders re-written by config_restore() */

/* This is a magic number we can use to detect validity */
uint16_t EEMEM eeprom_magic;
/* IP address configuration */
uint8_t EEMEM eeprom_v4[4];
uint8_t EEMEM eeprom_v4cidr;
uint8_t EEMEM eeprom_v4gw[4];

/* private prototypes */
void config_check(void);
void spam_version(FILE *where);

uint32_t jenkins_one_at_a_time_hash(uint8_t *key, uint8_t len);
void obtain_mac(twi_portname_t port, uint8_t *mac);

/* This is the main firmware entry point */

void main(void) {
    uint8_t idle;
    FILE *debugcon, *gps;

    /* FIXME: rewrite for VCXO init */

    /* enable the 32MHz OSC */
    clock_osc_run(osc_rc32mhz);
    /* switch to it */
    clock_sysclk(sclk_rc32mhz);

    /* enable interrupts */
    PMIC.CTRL = PMIC_HILVLEN_bm | PMIC_MEDLVLEN_bm | PMIC_LOLVLEN_bm;
 	sei();

    PORTA.DIRSET = PIN5_bm | PIN6_bm;

    flags = 0;
    set_sleep_mode(SLEEP_MODE_IDLE); /* just stop clocking CPU when required to idle */
    config_check();

    /* init some serial ports! */
    usart_init(usart_d0,64,128);
    usart_conf(usart_d0,921600,8,none,1,U_FEAT_NONE,&debugcon_hook);
    usart_run(usart_d0);
    debugcon = usart_map_stdio(usart_d0);

    /* this is required to force sync with the FTDI chip */
    putchar(0);
    _delay_ms(1);

#ifndef DEBUG_GPS_PASS
    console_open(0,debugcon,ch_mode_serial);
    console_version(debugcon);
#endif

    /* start passing through GPS noise */
    usart_init(usart_e0,256,64);
    usart_conf(usart_e0,9600,8,none,1,U_FEAT_NONE,&gps_hook);
    usart_run(usart_e0);
    gps = usart_map_stdio(usart_e0);

    /* init I2C port for both DAC and MAC EEPROM */
    twi_init(I2C_PORT_MAC,400,200);
    if (I2C_PORT_MAC != I2C_PORT_DAC) {
        twi_init(I2C_PORT_DAC,400,200);
    }

    {
        uint8_t mac[6], ip[4], cidr, gw[4];

        obtain_mac(I2C_PORT_MAC,mac);

        printf("mac: %02x:%02x:%02x:%02x:%02x:%02x\r\n",
            mac[0], mac[1], mac[2], mac[3], mac[4], mac[5]);

        eeprom_read_block(&ip,&eeprom_v4,4);
        eeprom_read_block(&gw,&eeprom_v4gw,4);
        cidr = eeprom_read_byte(&eeprom_v4cidr);

        /* do a hard reset */
        PORTC.DIRSET = PIN2_bm;
        PORTC.OUTCLR = PIN2_bm;
        _delay_ms(1);
        PORTC.OUTSET = PIN2_bm;
        _delay_ms(1);

        w5500_init(spi_c,&PORTC,PIN4_bm,mac);
        w5500_ip_conf(ip,cidr,gw);

        /* configure the interrupt for w5500 events */
        PORTC.DIRCLR = PIN3_bm;
        PORTC.PIN3CTRL = PORT_ISC_FALLING_gc;
        PORTC.INT0MASK |= PIN3_bm;
        PORTC.INTCTRL |= PORT_INT0LVL_LO_gc; /* low prio */
    }

    /* find out if the DAC is there */
    max580x_init(twi_c,0);
    max580x_set(twi_c,0,0x7fff);
    //printf("current value is %04x\r\n",max580x_read(twi_c,0));

    console_set_prompt(0,"ntpstick$ ");
    console_prompt(0);


    /* set up telnetd */
    //telnetd_listen(0,1);

    idle = 0;
    while (1) {
        if (flags & FLAG_DEBUGCON) {
            int c;

            flags &= ~(FLAG_DEBUGCON);
#ifndef DEBUG_GPS_PASS
            console_process(0);
#else
            while (1) {
                c = fgetc(debugcon);
                if (c == EOF) {
                    break;
                }
                fputc(c,gps);
            }
#endif
            //console_message(0,"Got char!");
        }
        if (flags & FLAG_GPS) {
            uint16_t x;
            uint8_t c[255], n = 0;

            flags &= ~(FLAG_GPS);
            /* process some GPS stuff, drain for now */
            while (fgetc(gps) != EOF);
        }
        if (flags & FLAG_W5500) {
            flags &= ~(FLAG_W5500);
            while (!(PORTC.IN & PIN3_bm)) {
                w5500_poll();
            }
        }
        idle++;
        cli();
        if (idle > 16) {
            idle = 0;
            /* go to sleep */
            sleep_enable();
            sei();
            sleep_cpu();
            sleep_disable();
        }
    }
}

void debugcon_hook(uint8_t c) {
    flags |= FLAG_DEBUGCON;
}

void gps_hook(uint8_t c) {
    if (c == '\n') {
        flags |= FLAG_GPS;
    }
}

/* this validates we have a valid configuration in the eeprom */
void config_check(void) {
    /* this will retrieve all required variables from the eeprom */
    /* first, check the validity of the eeprom signature, if it's invalid
     * then write defaults for the various values needed */
    if (eeprom_read_word(&eeprom_magic) != EEPROM_MAGIC) {
        uint8_t addr[4] = {10,32,34,8};
        eeprom_write_block((const void *)&addr,(void *)&eeprom_v4,4);
        eeprom_write_byte(&eeprom_v4cidr,24);
        memset(addr,0,4);
        eeprom_write_block((const void *)&addr,(void *)&eeprom_v4gw,4);
        /* now finish up with the writes for the magic number */
        eeprom_write_word(&eeprom_magic,EEPROM_MAGIC);
    }
}

ISR(PORTC_INT0_vect) {
    /* check to see if the level on PC2 is low */
    if (!(PORTC.IN & PIN3_bm)) {
        flags |= FLAG_W5500;
    }
}

/* function to populate a MAC address into the given struct */
void obtain_mac(twi_portname_t port, uint8_t *mac) {
    uint8_t n;

    /* first approach, find an I2C eeprom with useful characteristics
     * on the bus, we read from 0xFA-0xFF if we find one
     * any EEPROM will do but this is probably a 24AA02E48 MAC chip */
    for (n = 0x50; n <= 0x57; n++) {
        /* probe for a possible MAC chip */
        if (twi_start(port,n,twi_mode_write)) {
            continue; /* errored out */
        }
        /* have a device hailed, try to identify it */
        twi_write(port,"\xFA",1,twi_more);
        twi_start(port,n,twi_mode_read);
        twi_read(port,mac,6,twi_stop);
        return;
    }

    /* we don't have a MAC externally attached, therefore, make
     * one up */
    /* "locally administrated" MACs are xxxxxx1x in the first octect on
     * the wire. This is actually the 2nd digit if writen in typical hex
     * format, as x2, x6, xA, xE */
    {
        uint8_t serial[11]; /* 11 byte serial number */
        uint32_t hash;

        nvm_serial(serial); /* copy the serial number */
        hash = jenkins_one_at_a_time_hash(serial,11);
        mac[0] = 0x02;
        mac[1] = 0x00;
        mac[2] = (hash >> 24) & 0xff;
        mac[3] = (hash >> 16) & 0xff;
        mac[4] = (hash >> 8) & 0xff;
        mac[5] = (hash) & 0xff;
        printf("mac: [warn] using generated MAC address\r\n");
    }
    return;
}

/* copied largely from http://en.wikipedia.org/wiki/Jenkins_hash_function */
uint32_t jenkins_one_at_a_time_hash(uint8_t *key, uint8_t len)
{
    uint32_t hash;
    uint8_t i;

    for(hash = i = 0; i < len; ++i)
    {
        hash += key[i];
        hash += (hash << 10);
        hash ^= (hash >> 6);
    }
    hash += (hash << 3);
    hash ^= (hash >> 11);
    hash += (hash << 15);
    return hash;
}

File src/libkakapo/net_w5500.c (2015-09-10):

/* Copyright (C) 2014 David Zanetti
 *
 * This file is part of libkakapo.
 *
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
 * If not, see <http://www.gnu.org/licenses/>.
 */

/* Datasheet used:
 * http://wizwiki.net/wiki/lib/exe/fetch.php?media=products:w5500:w5500_ds_v102e_131114.pdf
 */

/* W5500 SPI comm structure
 * [addr1][addr0][blk/cmd][data][data]...
 * MSB transmission
 *
 * blk/cmd is broken up thus:
 * Block Address: 7-3
 * RWB: 2
 * Length: 1-0
 *
 * Length is 00 for variable length mode. we only implement variable */

#include <avr/io.h>
#include "global.h"
#include <stdio.h>
#include <avr/pgmspace.h>
#include <stdlib.h>
#include <string.h>
#include "spi.h"
#include "net_w5500.h"
#include "errors.h"

#include "debug.h"

/* W5500 Comms flags */
#define RWB 0x4 /**< Read/Write Bit, set is write */

/* W5500 block select (as needed for command block) */
#define BLK_COMMON 0x0 /**< Common block is 0 */
#define BLK_SOCKET_REG(n) (((n << 2)+1) << 3) /**< Socket N register block */
#define BLK_SOCKET_TX(n) (((n << 2)+2) << 3) /**< Socket N TX buffer block */
#define BLK_SOCKET_RX(n) (((n << 2)+3) << 3) /**< Socket N RX buffer block */

/* W5500 Register Map for common block */
#define COM_MR 0x00			/**< Mode */
#define COM_GAR0 0x01		/**< Gateway Octet 0 (MSB) */
#define COM_GAR1 0x02		/**< Gateway Octet 1 */
#define COM_GAR2 0x03		/**< Gateway Octet 2 */
#define COM_GAR3 0x04		/**< Gateway Octet 3 (LSB) */
#define COM_SUBR0 0x05		/**< Subnet Mask Octet 0 (MSB) */
#define COM_SUBR1 0x06		/**< Subnet Mask Octet 1 */
#define COM_SUBR2 0x07		/**< Subnet Mask Octet 2 */
#define COM_SUBR3 0x08		/**< Subnet Mask Octet 3 (LSB) */
#define COM_SHAR0 0x09		/**< Source HW MAC Octet 0 (MSB) */
#define COM_SHAR1 0x0a		/**< Source HW MAC Octet 1 */
#define COM_SHAR2 0x0b		/**< Source HW MAC Octet 2 */
#define COM_SHAR3 0x0c		/**< Source HW MAC Octet 3 */
#define COM_SHAR4 0x0d		/**< Source HW MAC Octet 4 */
#define COM_SHAR5 0x0e		/**< Source HW MAC Octet 5 (LSB) */
#define COM_SIPR0 0x0f		/**< Source IP Octet 0 (MSB) */
#define COM_SIPR1 0x10		/**< Source IP Octet 1 */
#define COM_SIPR2 0x11		/**< Source IP Octet 2 */
#define COM_SIPR3 0x12		/**< Source IP Octet 3 (LSB) */
#define COM_INTLEVEL0 0x13	/**< Interrupt Low Level Timer (MSB) */
#define COM_INTLEVEL1 0x14	/**< Interrupt Low Level Timer (LSB) */
#define COM_IR 0x15			/**< Interrupt */
#define COM_IMR 0x16		/**< Interrupt Mask */
#define COM_SIR 0x17		/**< Socket Interrupt */
#define COM_SIMR 0x18		/**< Socket Interrupt Mask */
#define COM_RTR0 0x19		/**< Retry Time (MSB) */
#define COM_RTR1 0x1a		/**< Retry Time (LSB) */
#define COM_RCR 0x1b		/**< Retry Count */
#define COM_PTIMER 0x1c		/**< PPP LCP Request Timer */
#define COM_PMAGIC 0x1d		/**< PPP LCP Magic Number */
#define COM_PHAR0 0x1e		/**< PPP Dest HW MAC Octet 0 (MSB) */
#define COM_PHAR1 0x1f		/**< PPP Dest HW MAC Octet 1 */
#define COM_PHAR2 0x20		/**< PPP Dest HW MAC Octet 2 */
#define COM_PHAR3 0x21		/**< PPP Dest HW MAC Octet 3 */
#define COM_PHAR4 0x22		/**< PPP Dest HW MAC Octet 4 */
#define COM_PHAR5 0x23		/**< PPP Dest HW MAC Octet 5 (LSB) */
#define COM_PSID0 0x24		/**< PPP Session ID (MSB) */
#define COM_PSID1 0x25		/**< PPP Session ID (LSB) */
#define COM_PMRU0 0x26		/**< PPP MSS (MSB) */
#define COM_PMRU1 0x27		/**< PPP MSS (LSB) */
#define COM_UIPR0 0x28		/**< Unreach IP Octet 0 (MSB) */
#define COM_UIPR1 0x29		/**< Unreach IP Octet 1 */
#define COM_UIPR2 0x2a		/**< Unreach IP Octet 2 */
#define COM_UIPR3 0x2b		/**< Unreach IP Octet 3 (LSB) */
#define COM_UPORTR0 0x2c	/**< Unreach Port (MSB) */
#define COM_UPORTR1 0x2d	/**< Unreach Port (LSB) */
#define COM_PHRCFGR 0x2e	/**< PHY Configuration */
/* 0x2f - 0x28 reserved */
#define COM_VERSIONR 0x39	/**< Chip Version */
/* 0x3a - 0xffff reserved */

/* W5500 Socket Register */
#define SOCK_MR 0x00		/**< Socket Mode */
#define SOCK_CR 0x01		/**< Socket Command */
#define SOCK_IR 0x02		/**< Socket Interrupt */
#define SOCK_SR 0x03		/**< Socket Status */
#define SOCK_PORT0 0x04		/**< Socket Source Port (MSB) */
#define SOCK_PORT1 0x05		/**< Socket Source Port (LSB) */
#define SOCK_DHAR0 0x06		/**< Socket Dest HW MAC Octet 0 (MSB) */
#define SOCK_DHAR1 0x07		/**< Socket Dest HW MAC Octet 1 */
#define SOCK_DHAR2 0x08		/**< Socket Dest HW MAC Octet 2 */
#define SOCK_DHAR3 0x09		/**< Socket Dest HW MAC Octet 3 */
#define SOCK_DHAR4 0x0a		/**< Socket Dest HW MAC Octet 4 */
#define SOCK_DHAR5 0x0b		/**< Socket Dest HW MAC Octet 5 (LSB) */
#define SOCK_DIPR0 0x0c		/**< Socket Dest IP Octet 0 (MSB) */
#define SOCK_DIPR1 0x0d		/**< Socket Dest IP Octet 1 */
#define SOCK_DIPR2 0x0e		/**< Socket Dest IP Octet 2 */
#define SOCK_DIPR3 0x0f		/**< Socket Dest IP Octet 3 (LSB) */
#define SOCK_DPORT0 0x10	/**< Socket Dest Port (MSB) */
#define SOCK_DPORT1 0x11	/**< Socket Dest Port (LSB) */
#define SOCK_MSSR0 0x12		/**< Socket MSS (MSB) */
#define SOCK_MSSR1 0x13		/**< Socket MSS (LSB) */
/* 0x14 reserved */
#define SOCK_TOS 0x15		/**< Socket IP TOS */
#define SOCK_TTL 0x16		/**< Socket IP TTL */
/* 0x17 - 0x1d reserved */
#define SOCK_RXBUF_SIZE 0x1e /**< Socket RX Buffer Size */
#define SOCK_TXBUF_SIZE 0x1f /**< Socket TX Buffer Size */
#define SOCK_TX_FSR0 0x20	/**< Socket TX Free Size (MSB) */
#define SOCK_TX_FSR1 0x21	/**< Socket TX Free Size (LSB) */
#define SOCK_TX_RD0 0x22	/**< Socket TX Read Pointer (MSB) */
#define SOCK_TX_RD1 0x23	/**< Socket TX Read Pointer (LSB) */
#define SOCK_TX_WR0 0x24	/**< Socket TX Write Pointer (MSB) */
#define SOCK_TX_WR1 0x25	/**< Socket TX Write Pointer (LSB) */
#define SOCK_RX_RSR0 0x26	/**< Socket RX Received Size (MSB) */
#define SOCK_RX_RSR1 0x27	/**< Socket RX Received Size (LSB) */
#define SOCK_RX_RD0 0x28	/**< Socket RX Read Pointer (MSB) */
#define SOCK_RX_RD1 0x29	/**< Socket RX Read Pointer (LSB) */
#define SOCK_RX_WR0 0x2a	/**< Socket RX Write Pointer (MSB) */
#define SOCK_RX_WR1 0x2b	/**< Socket RX Write Pointer (LSB) */
#define SOCK_IMR 0x2c		/**< Socket Interrupt Mask */
#define SOCK_FRAG0 0x2d		/**< Socket Fragment Offset IP Hdr (MSB) */
#define SOCK_FRAG1 0x2e		/**< Socket Fragment Offset IP Hdr (LSB) */
#define SOCK_KPALVTR 0x2f	/**< Socket Keepalive Timer */
/* 0x30 - 0xffff reserved */
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

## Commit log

2014-11-10 Initial cut of hardware source files
    [ntpstick-1-ethernet.sch, ntpstick-1-gps.sch, ntpstick-1-system.sch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]
2014-11-10 Gerbers most recently generated.
    [ntpstick-1-B_Cu.gbl, ntpstick-1-B_Mask.gbs, ntpstick-1-B_SilkS.gbo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]
2014-11-10 License and README for gerbers
2014-11-10 License and README for Kicad Source files
2014-11-10 Add schematic as PDF
2014-11-11 Gerbers sent for panelisation on 20141111
    [ntpstick-1-B_Cu.gbl, ntpstick-1-B_Mask.gbs, ntpstick-1-B_SilkS.gbo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]
2014-11-14 Add codeblocks stuff to ignore filter
2014-12-13 Switch to single event handler in driver code. This resyncs us with libkakapo mainline
2015-02-06 Remove TWI code that was being reworked now it's in libkakapo mainline.
    [max580x.c]
2015-03-29 Version 1.2 HW design
    [ntpstick-1-B_Cu.gbl, ntpstick-1-B_Mask.gbs, ntpstick-1-B_SilkS.gbo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]
2015-03-29 Update specs to current
2015-03-29 Fix up 1.2 schematics
2015-09-10 Remove schematic file no longer used
    [ntpstick-1-gps.sch]
2015-09-10 Final manufactured version of 1.2 HW
    [ntpstick-1-ethernet.sch, ntpstick-1-system.sch, ntpstick-1.kicad_pcb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]
2015-09-10 Gerbers for HW 1.2 actually manufactured
    [ntpstick-1-B_Cu.gbl, ntpstick-1-B_Mask.gbs, ntpstick-1-B_SilkS.gbo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]
2015-09-10 Remove extra schematic copy that slipped in at some stage
2015-09-10 Update 1.2 HW schematic to final version

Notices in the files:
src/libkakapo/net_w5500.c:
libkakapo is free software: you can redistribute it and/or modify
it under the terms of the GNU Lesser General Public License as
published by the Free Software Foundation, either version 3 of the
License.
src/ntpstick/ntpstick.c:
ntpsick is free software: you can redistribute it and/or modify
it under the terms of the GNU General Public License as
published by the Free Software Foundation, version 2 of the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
